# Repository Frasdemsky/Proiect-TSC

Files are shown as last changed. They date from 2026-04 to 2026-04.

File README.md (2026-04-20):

# Proiect-TSC - ceas

am tras trase printre pini in loc de via pentru ca nu stiam la acel moment ca pot pune via pe pin si sa fie in regula

Extras din BOM


Descrierea Funcționalității Hardware

Smartwatch-ul InkTime este construit în jurul microcontroller-ului nRF52840, ideal pentru aplicații open-source și comunicație eficientă energetic.

  Sistemul de Alimentare: Încărcarea se face prin mufa USB-C, care beneficiază de protecție ESD prin dioda USBLC6-2SC6Y. Integratul BQ25180YBGR încarcă bateria LiPo. Deoarece tensiunea bateriei variază pe măsură ce se descarcă, un convertor de tip Buck-Boost (RT6160AWSC) menține tensiunea sistemului stabilă la 3.3V. Circuitul integrat MAX17048G+T10 funcționează ca Fuel Gauge pe I2C pentru a raporta precis nivelul bateriei către microcontroller.
  
  Afișaj E-Paper: Este conectat la placă printr-un port dedicat (E-Paper Display Connector). Pentru o eficiență energetică maximă, alimentarea ecranului trece printr-un tranzistor MOSFET (DMG2305UX), permițând oprirea completă a curentului către display prin semnalul R_PWR_EPD atunci când imaginea nu se actualizează.
  
  Senzori și Interacțiune: Detecția orientării și a pașilor se face prin senzorul IMU BMA421, conectat prin interfața I2C (TP_SCL și TP_SDA). Pentru feedback la notificări sau apăsări de butoane, sistemul folosește un motor haptic controlat de driver-ul DRV2605YZFR. Interacțiunea manuală se face prin 3 butoane fizice (Up, Enter, Down) decuplate capacitiv.

Alocarea Pinilor nRF52840

  Magistrala I2C: Pinii de pe MCU asociați cu net-urile TP_SCL și TP_SDA conectează senzorul IMU BMA421, circuitul Fuel Gauge MAX17048 și driver-ul haptic DRV2605YZFR.
  Butoane: Butoanele SW_UP, SW_ENT și SW_DN sunt direcționate către pini GPIO ai nRF52840.
  
  Interfața SWD: Programarea și debugging-ul se realizează exclusiv prin pad-urile de test TP_SWDIO, TP_SWDCLK și TP_RESET.
  
  Control E-Paper: Comunicarea cu display-ul se face printr-o magistrală ce ajunge la conectorul E-Paper (include pini SPI și semnale de control). Controlul alimentării se realizează prin pinul conectat la R_PWR_EPD.

Am decis sa accept erorile de via pe pini pentru ca asa a spus Dan pe teams ca putem face. poze cu pcb-ul in carcasa se afla in folderul de images.
Puteam sa pun mai central acel MCU si sa am o organizare mai buna.

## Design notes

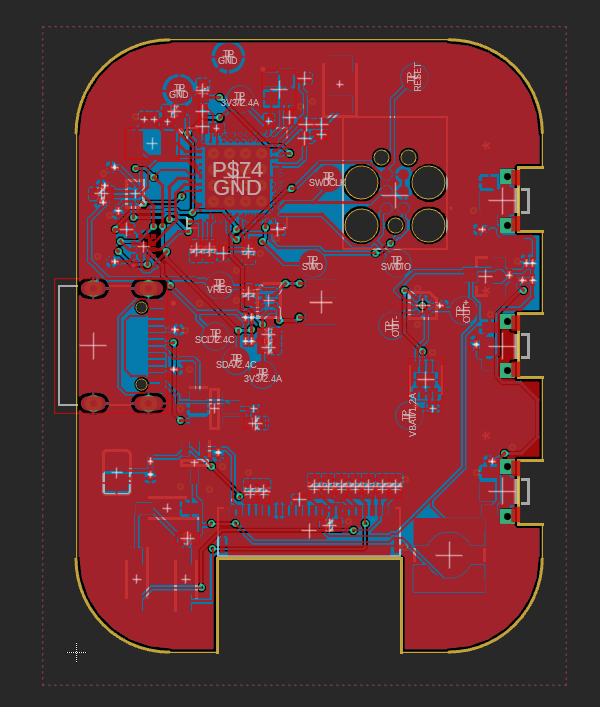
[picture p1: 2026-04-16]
Images/2DpcbPoligon.png

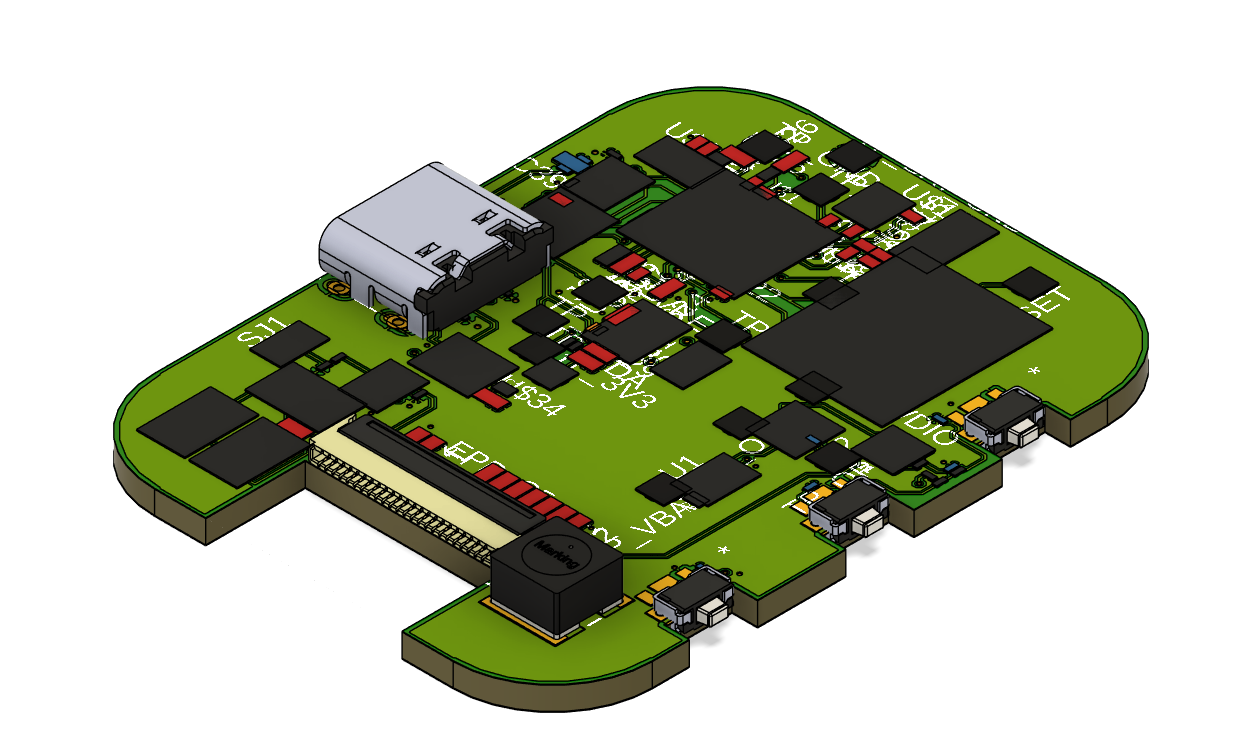
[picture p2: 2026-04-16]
Images/3DpcbGNDlayer.png

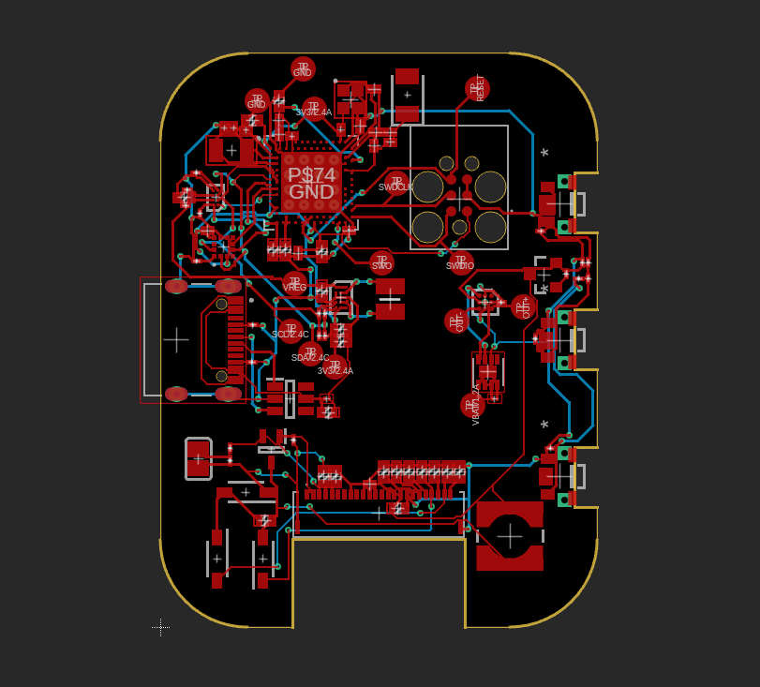
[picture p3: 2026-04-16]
Images/2DpcbVisible.png

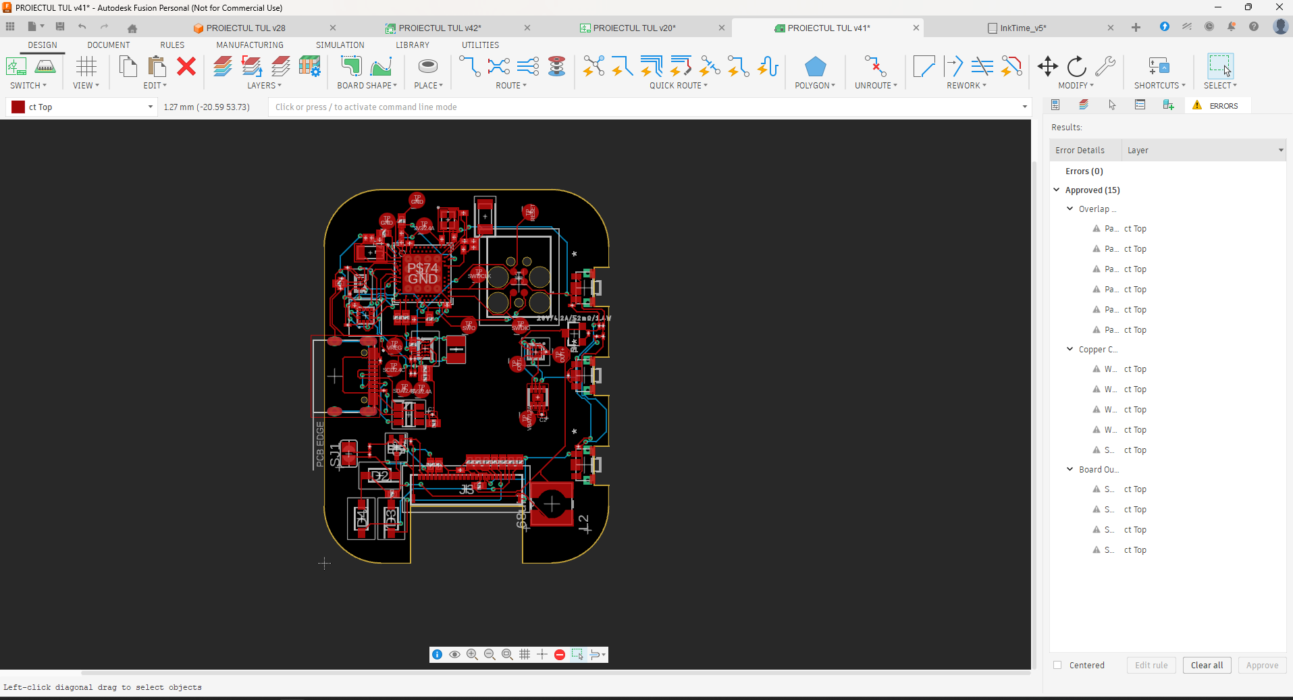
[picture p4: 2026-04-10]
Images/2D PCB.png

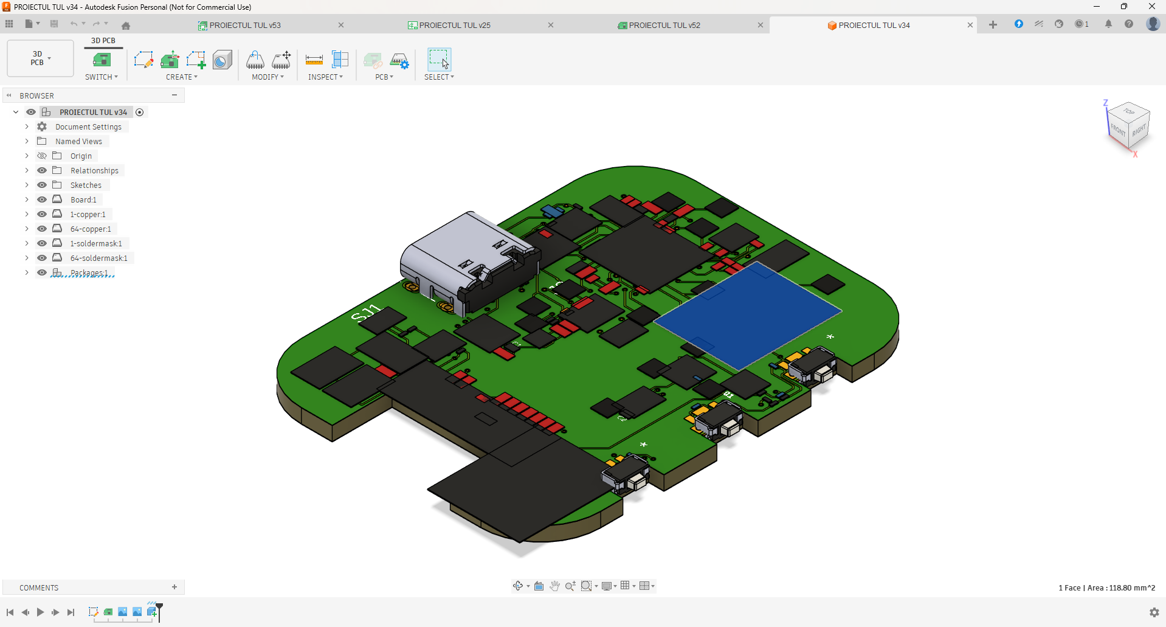
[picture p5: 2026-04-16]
Images/3D pcb.png

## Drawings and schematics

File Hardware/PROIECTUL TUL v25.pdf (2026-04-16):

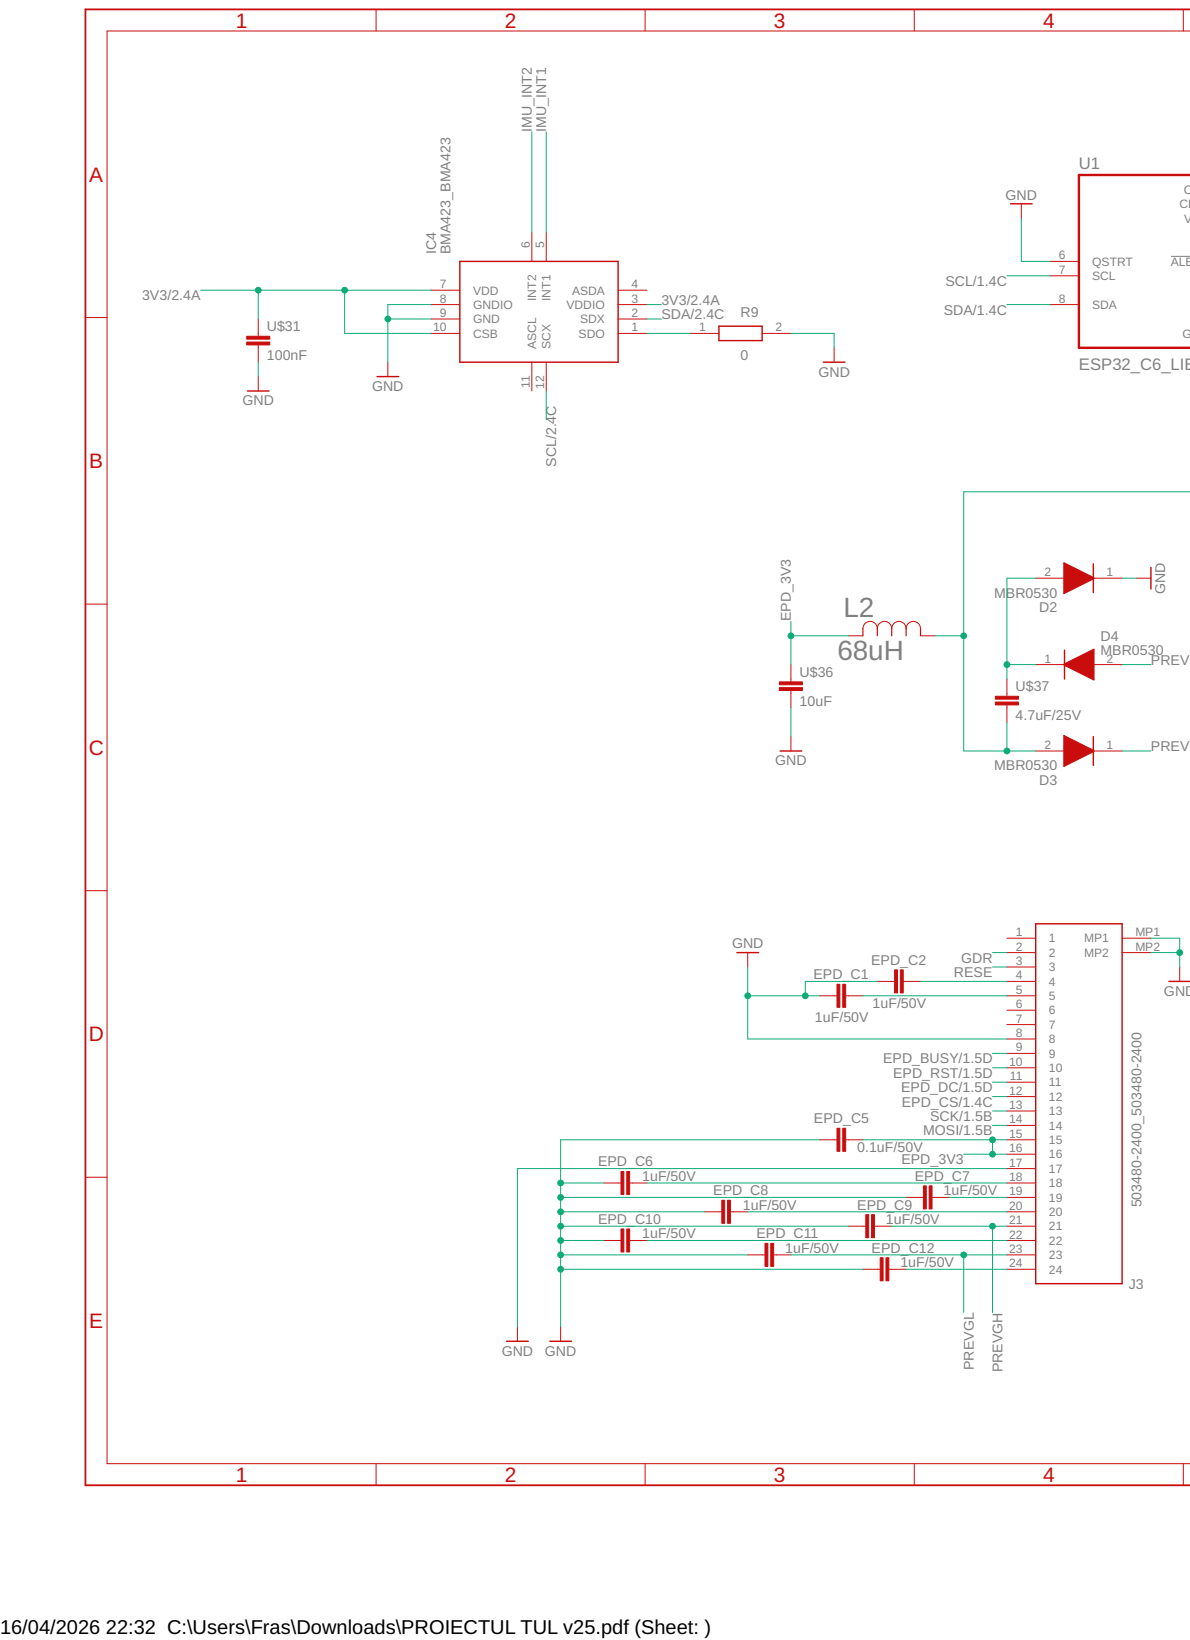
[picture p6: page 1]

1uF/50V EPD_C7 18

EPD_C8 | 1uF/50V 19
1uF/50V EPD_C9 | 20

EPD_C10 | | 1uF/50V 21

1uF/50V EPD_C11 | | 22

1uF/50V EPD_C12 | 23

16/04/2026 22:32 C:\Users\Fras\Downloads\PROIECTUL TUL v25.pdf (Sheet: )

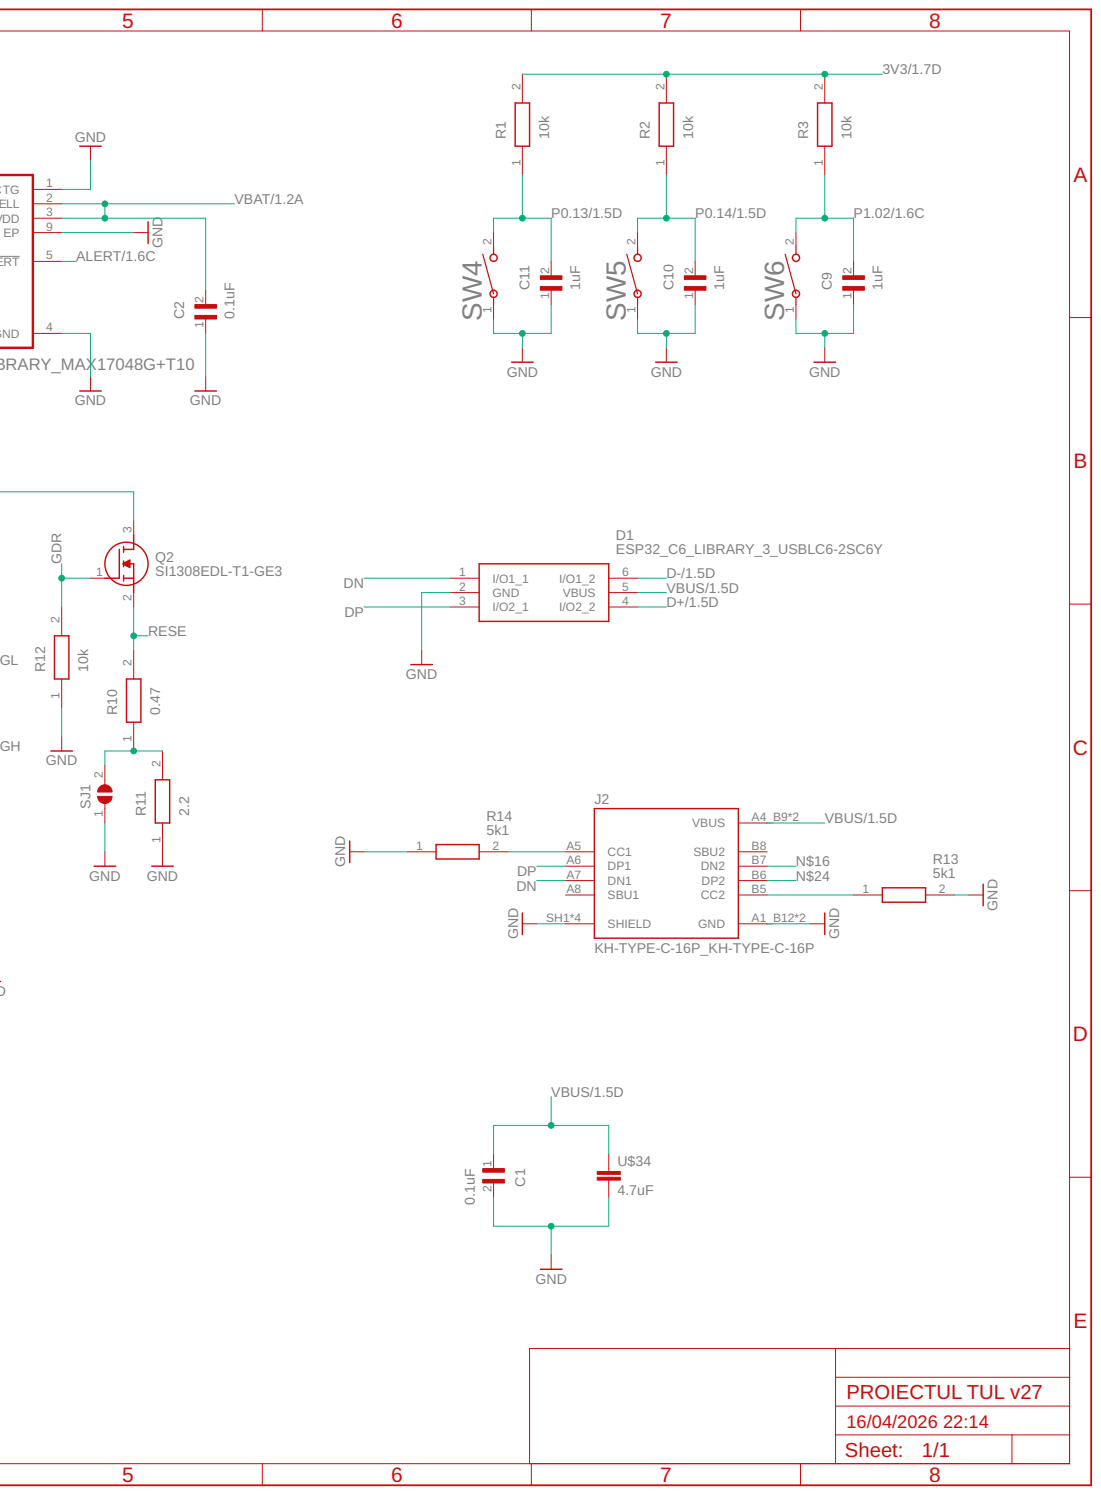
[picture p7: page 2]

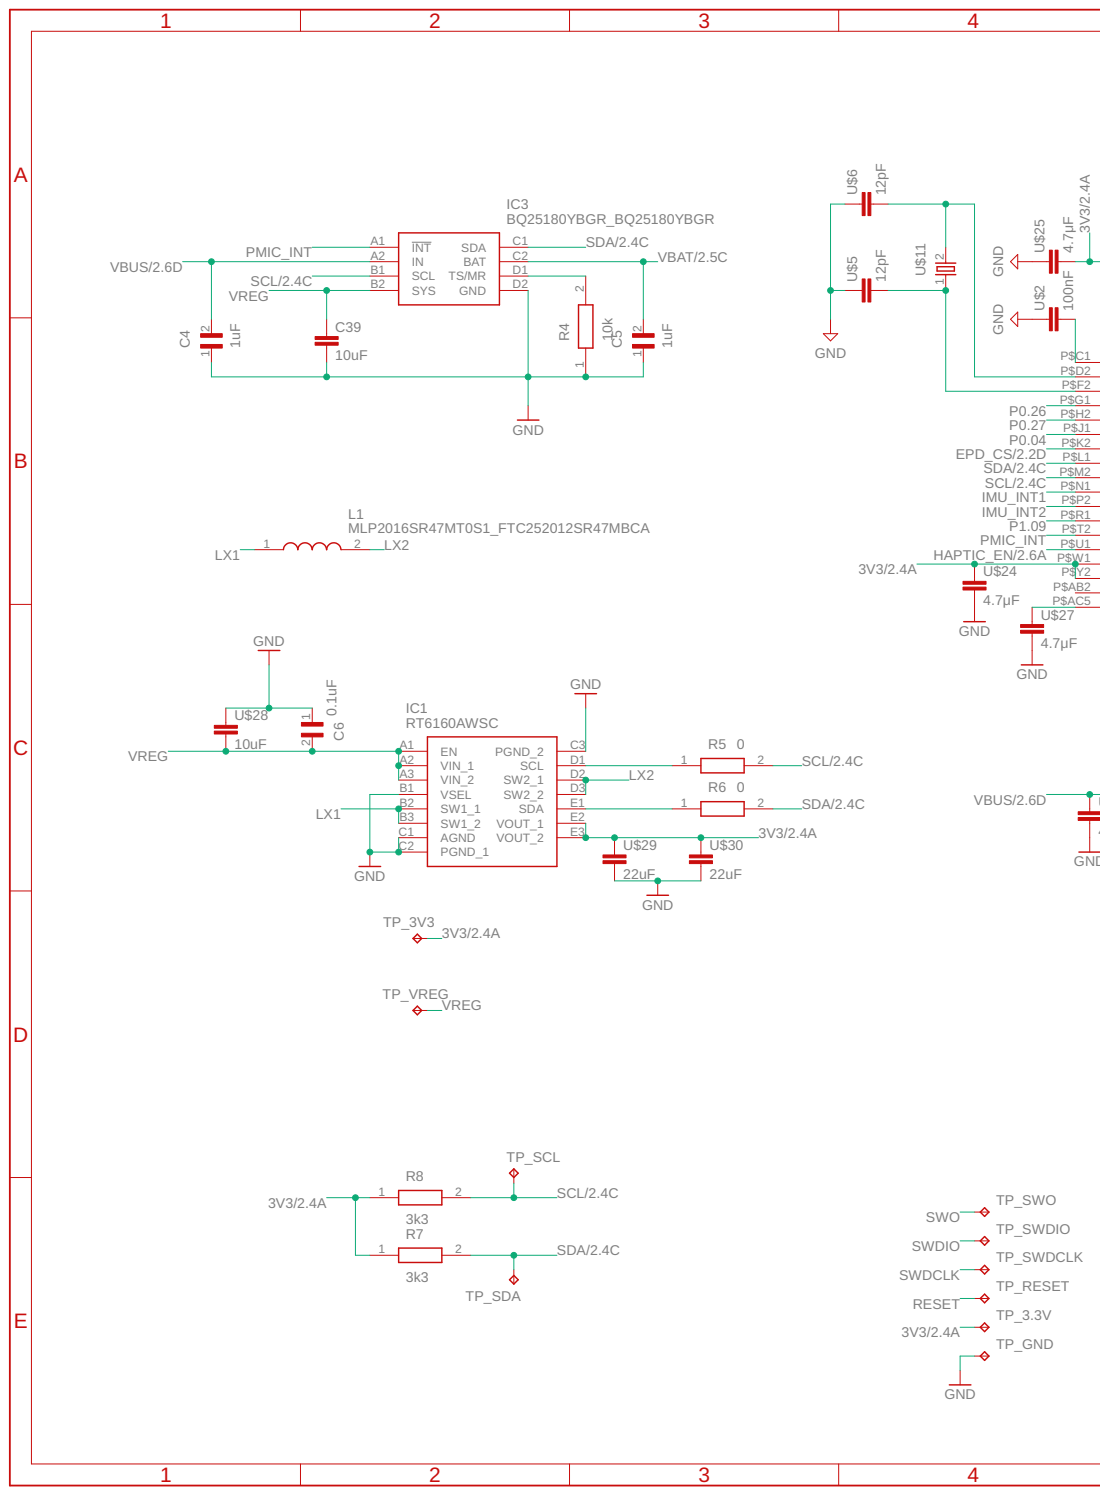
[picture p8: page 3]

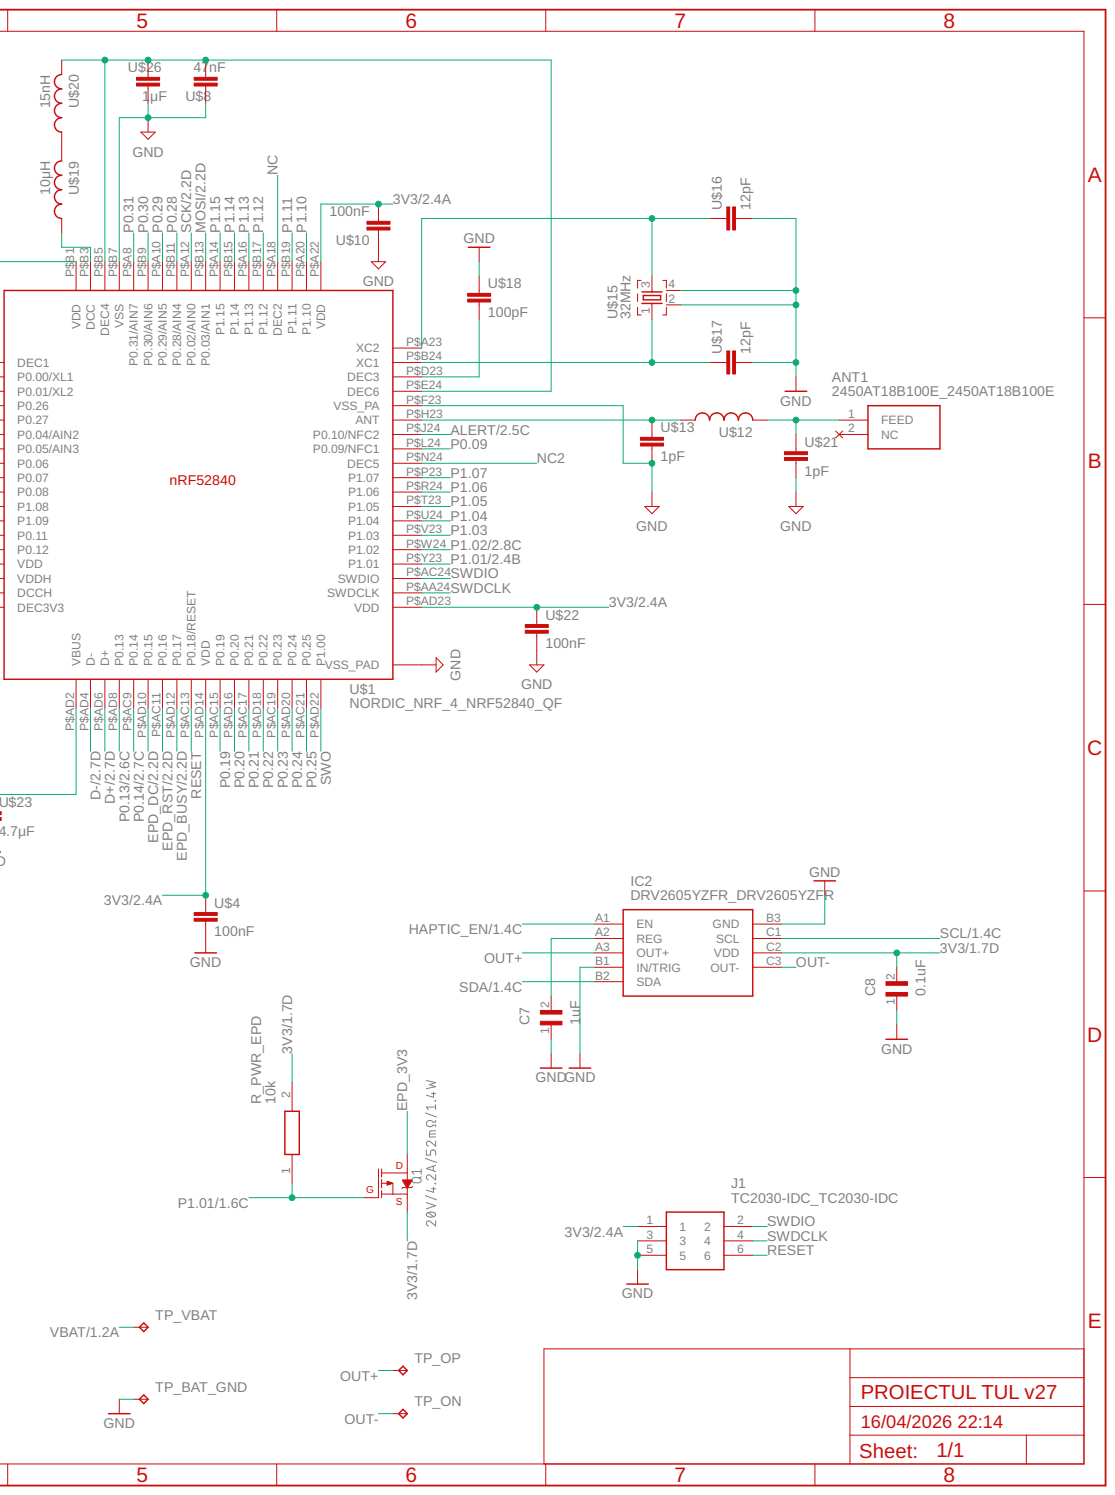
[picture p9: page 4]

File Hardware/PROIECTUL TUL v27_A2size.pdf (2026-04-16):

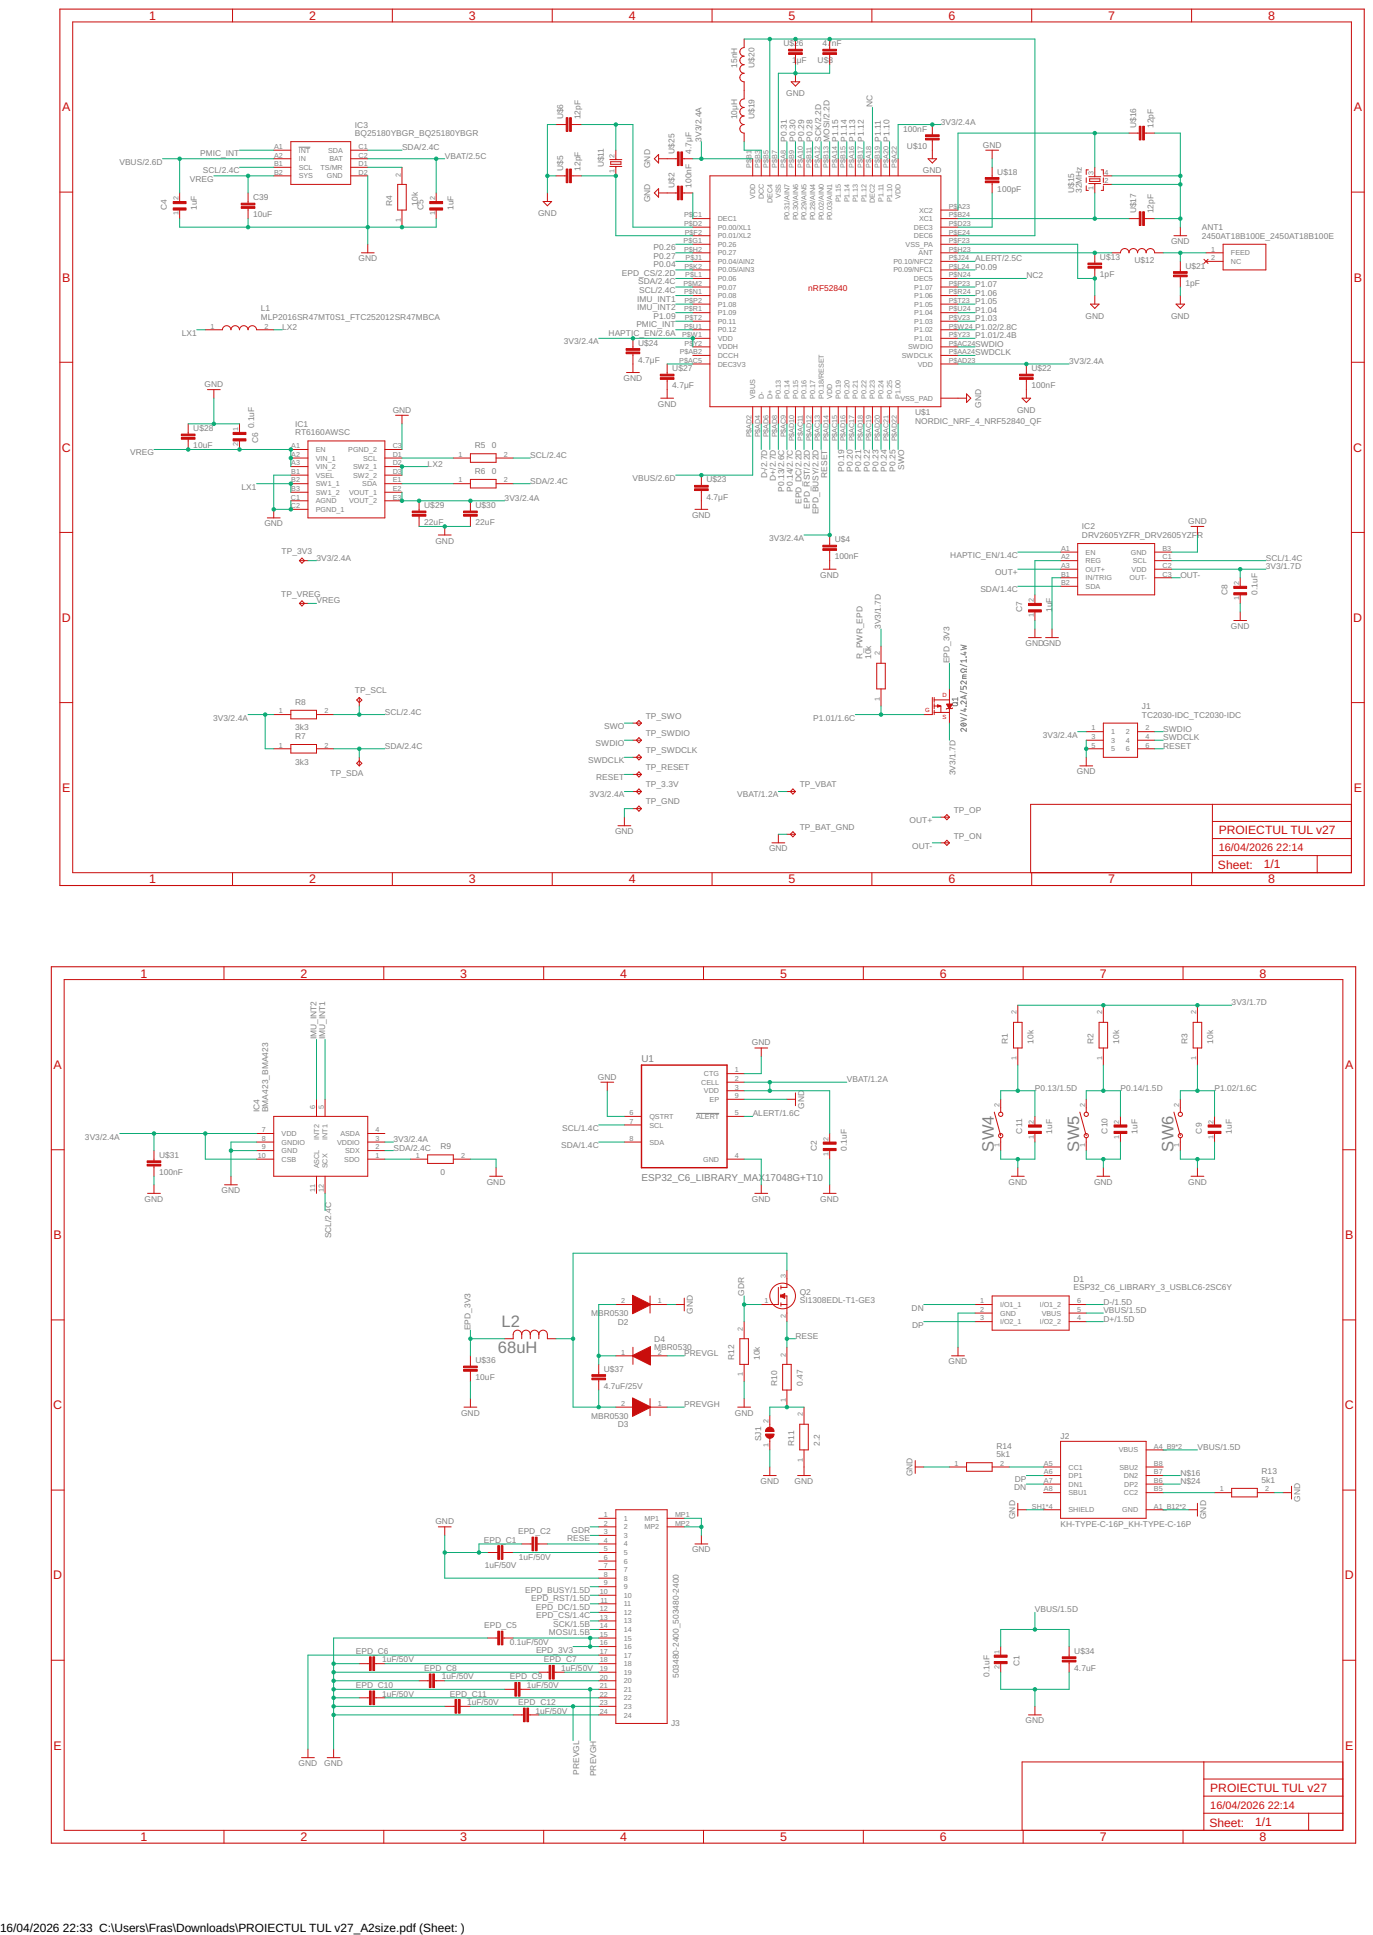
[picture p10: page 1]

1uF/50V EPD_C7 18

EPD_C8 | 1uF/50V 19
1uF/50V EPD_C9 | 20

EPD_C10 | | 1uF/50V 21

1uF/50V EPD_C11 | | 22

1uF/50V EPD_C12 | 23

16/04/2026 22:33 C:\Users\Fras\Downloads\PROIECTUL TUL v27_A2size.pdf (Sheet: )

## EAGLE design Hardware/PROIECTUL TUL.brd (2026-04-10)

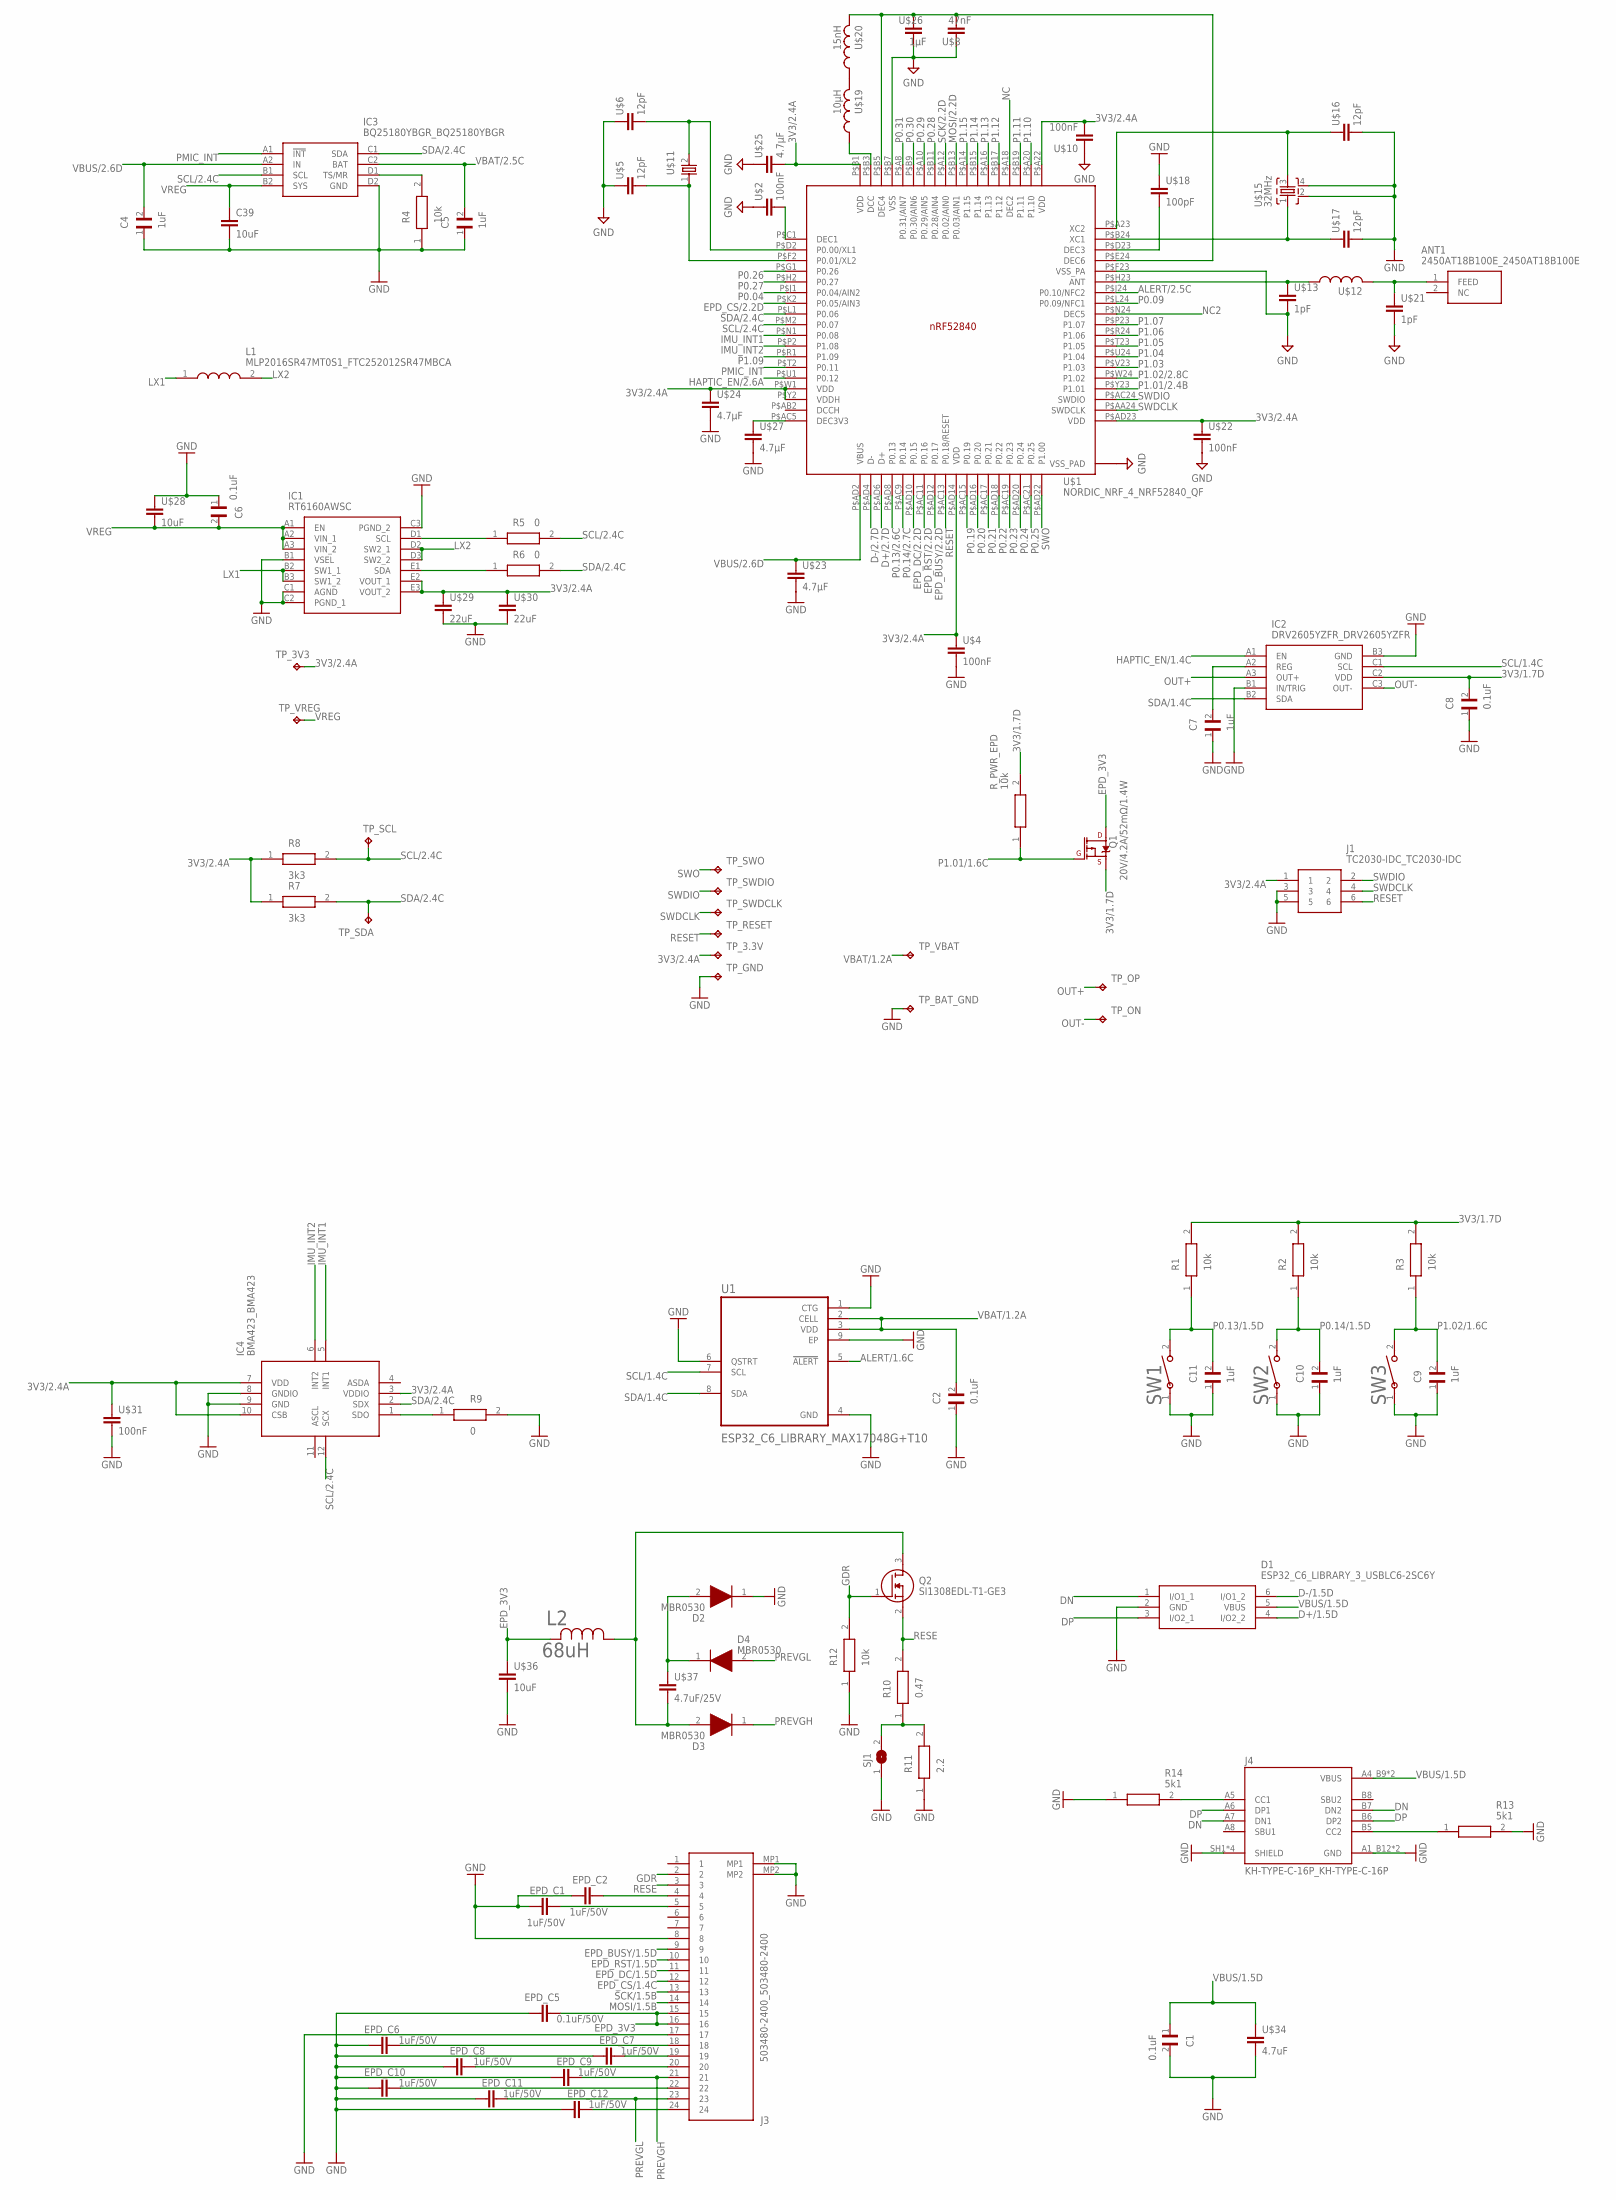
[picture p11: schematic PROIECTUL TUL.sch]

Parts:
ANT1: 2450AT18B100E_2450AT18B100E; 2450AT18B100E_ANTC3216X140N
C1, C2: 0.1uF; GRM011R60J152KE01L_2_CAPC0201X13N
C4, C5, C7, C9, C10, C11: 1uF; GRM011R60J152KE01L_1_0201
C6, C8: 0.1uF; GRM011R60J152KE01L_1_0201
C39: 10uF; NORDIC_NRF_3_RESC0402_L
D1: ESP32_C6_LIBRARY_3_USBLC6-2SC6Y; ESP32_C6_LIBRARY_3_SOT95P280X145-6N
D2, D3, D4: MBR0530; ESP32_C6_LIBRARY_5_SOD3716X135N
EPD_C1, EPD_C2, EPD_C6, EPD_C7, EPD_C8, EPD_C9, EPD_C10, EPD_C11, EPD_C12: 1uF/50V; NORDIC_NRF_3_RESC0402_L
EPD_C5: 0.1uF/50V; NORDIC_NRF_3_RESC0201_L
IC1: RT6160AWSC; RT6160AWSC_BGA15C40P3X5_140X230X60
IC2: DRV2605YZFR_DRV2605YZFR; DRV2605YZFR_BGA9C50P3X3_144X144X62
IC3: BQ25180YBGR_BQ25180YBGR; BQ25180YBGR_BGA8C40P2X4_100X155X50
IC4: BMA423_BMA423
J1: TC2030-IDC_TC2030-IDC; TC2030-IDC_TC2030IDC
J3: 503480-2400_503480-2400; 503480-2400_5034802400
J4: KH-TYPE-C-16P_KH-TYPE-C-16P; KH-TYPE-C-16P_KINGHELM_KH-TYPE-C-16P
L1: MLP2016SR47MT0S1_FTC252012SR47MBCA; MLP2016SR47MT0S1_INDC2016X100N
L2: 68uH; ESP32_C6_LIBRARY_2_IND_4828-WE-TPC_WRE
Q1: 20V/4.2A/52mΩ/1.4W; ESP32_C6_LIBRARY_4_ESP32_C6_LIBRARY_4_ESP32_C6_LIBRARY_4_ES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
Q2: SI1308EDL-T1-GE3; ESP32_C6_LIBRARY_6_SOT65P210X110-3N
R1, R3, R4, R12: 10k; ERA-1AEB3401C_0201
R2: 10k; CPF0201D7K68C1_0201
R5: 0; CPF0201D7K68C1_0201
R6, R9: 0; ERA-1AEB3401C_0201
R7, R8: 3k3; ERA-1AEB3401C_0201
R10: 0.47; ERA-1AEB3401C_0201
R11: 2.2; ERA-1AEB3401C_0201
R13, R14: 5k1; ERA-1AEB3401C_0201
R_PWR_EPD: 10k; ERA-1AEB3401C_0201
SJ1: ESP32_C6_LIBRARY_7_JUMPER_SJ
SW1, SW2, SW3: 2025-10-22_07-23-44_LIBRARY_EVP-AKE31ASW_EVP-AKE3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; 2025-10-22_07-23-44_LIBRARY_SW_EVP-AKE31A_PAN
TP_3.3V, TP_3V3: HECTOR_WATCH_1_TPTP20R; HECTOR_WATCH_1_TP20R
TP_BAT_GND: HECTOR_WATCH_1_TPTP20R; HECTOR_WATCH_1_TP20R
TP_GND: HECTOR_WATCH_1_TPTP20R; HECTOR_WATCH_1_TP20R
TP_ON: HECTOR_WATCH_1_TPTP20R; HECTOR_WATCH_1_TP20R
TP_OP: HECTOR_WATCH_1_TPTP20R; HECTOR_WATCH_1_TP20R
TP_RESET: HECTOR_WATCH_1_TPTP20R; HECTOR_WATCH_1_TP20R
TP_SCL: HECTOR_WATCH_1_TPTP20R; HECTOR_WATCH_1_TP20R
TP_SDA: HECTOR_WATCH_1_TPTP20R; HECTOR_WATCH_1_TP20R
TP_SWDCLK: HECTOR_WATCH_1_TPTP20R; HECTOR_WATCH_1_TP20R
TP_SWDIO: HECTOR_WATCH_1_TPTP20R; HECTOR_WATCH_1_TP20R
TP_SWO: HECTOR_WATCH_1_TPTP20R; HECTOR_WATCH_1_TP20R
TP_VBAT: HECTOR_WATCH_1_TPTP20R; HECTOR_WATCH_1_TP20R
TP_VREG: HECTOR_WATCH_1_TPTP20R; HECTOR_WATCH_1_TP20R
U1: ESP32_C6_LIBRARY_MAX17048G+T10; ESP32_C6_LIBRARY_SON50P200X200X80-9N
U$1: NORDIC_NRF_4_NRF52840_QF; NORDIC_NRF_4_AQFN50P700X700X85_HS-74N
U$2, U$10: 100nF; RESC0201_L
U$4, U$22, U$31: 100nF; NORDIC_NRF_3_RESC0201_L
U$5, U$6: 12pF; RESC0201_L
U$8: 47nF; RESC0201_L
U$11: NORDIC_NRF_1_XTAL_32KHZ; NORDIC_NRF_1_XTAL_3215_N
U$12: NORDIC_NRF_2_INDUCTOR_0201_L; NORDIC_NRF_2_RESC0201_L
U$13, U$21: 1pF; NORDIC_NRF_3_RESC0201_L
U$15: 32MHz; NORDIC_NRF_BT-XTAL_2016_N
U$16, U$17: 12pF; NORDIC_NRF_3_RESC0201_L
U$18: 100pF; NORDIC_NRF_3_RESC0201_L
U$19: 10μH; NORDIC_NRF_2_RESC0201_L
U$20: 15nH; NORDIC_NRF_2_RESC0201_L
U$23, U$24, U$25, U$27: 4.7μF; NORDIC_NRF_3_RESC0402_L
U$26: 1μF; NORDIC_NRF_3_RESC0402_L
U$28, U$36: 10uF; NORDIC_NRF_3_RESC0402_L
U$29, U$30: 22uF; NORDIC_NRF_3_RESC0402_L
U$34: 4.7uF; NORDIC_NRF_3_RESC0402_L
U$37: 4.7uF/25V; NORDIC_NRF_3_RESC0402_L

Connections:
3V3/1.7D: C8.2, IC2.C2 (VDD), Q1.2 (S), R1.2, R2.2, R3.2, R_PWR_EPD.2
3V3/2.4A: IC1.E2 (VOUT_1), IC1.E3 (VOUT_2), IC4.3 (VDDIO), IC4.7 (VDD), IC4.10 (CSB), J1.1, R7.1, R8.1, TP_3.3V.TP, TP_3V3.TP, U$1.P$A22 (VDD), U$1.P$AD14 (VDD), U$1.P$AD23 (VDD), U$1.P$B1 (VDD), U$1.P$W1 (VDD), U$1.P$Y2 (VDDH), U$4.1, U$10.2, U$22.1, U$24.1, U$25.2, U$29.1, U$30.1, U$31.1
ALERT/1.6C: U1.5 (!ALERT)
ALERT/2.5C: U$1.P$J24 (P0.10/NFC2)
D+/1.5D: D1.4 (I/O2_2)
D+/2.7D: U$1.P$AD6 (D+)
D-/1.5D: D1.6 (I/O1_2)
D-/2.7D: U$1.P$AD4 (D-)
DN: D1.1 (I/O1_1), J4.A7 (DN1), J4.B7 (DN2)
DP: D1.3 (I/O2_1), J4.A6 (DP1), J4.B6 (DP2)
EPD_3V3: EPD_C5.2, J3.15, J3.16, L2.2, Q1.3 (D), U$36.1
EPD_BUSY/1.5D: J3.9
EPD_BUSY/2.2D: U$1.P$AD12 (P0.17)
EPD_CS/1.4C: J3.12
EPD_CS/2.2D: U$1.P$K2 (P0.05/AIN3)
EPD_DC/1.5D: J3.11
EPD_DC/2.2D: U$1.P$AD10 (P0.15)
EPD_RST/1.5D: J3.10
EPD_RST/2.2D: U$1.P$AC11 (P0.16)
GDR: J3.2, Q2.1 (G), R12.2
GND: C1.2, C2.1, C4.1, C5.1, C6.1, C7.1, C8.1, C9.1, C10.1, C11.1, C39.2, D1.2 (GND), D2.1 (K), EPD_C1.1, EPD_C2.1, EPD_C5.1, EPD_C6.1, EPD_C7.1, EPD_C8.1, EPD_C9.1, EPD_C10.1, EPD_C11.1, EPD_C12.1, IC1.B1 (VSEL), IC1.C1 (AGND), IC1.C2 (PGND_1), IC1.C3 (PGND_2), IC2.B1 (IN/TRIG), IC2.B3 (GND), IC3.D2 (GND), IC4.8 (GNDIO), IC4.9 (GND), J1.3, J1.5, J3.8, J3.17, J3.MP1, J3.MP2, J4.A1_B12 (GND), J4.A12_B1 (GND), J4.SH1 (SHIELD), J4.SH2 (SHIELD), J4.SH3 (SHIELD), J4.SH4 (SHIELD), R4.1, R9.2, R11.1, R12.1, R13.2, R14.1, SJ1.1, SW1.1, SW2.1, SW3.1, TP_BAT_GND.TP, TP_GND.TP, U1.1 (CTG), U1.4 (GND), U1.6 (QSTRT), U1.9 (EP), U$1.P$74 (VSS_PAD), U$1.P$75 (VSS_PAD), U$1.P$76 (VSS_PAD), U$1.P$77 (VSS_PAD), U$1.P$78 (VSS_PAD), U$1.P$79 (VSS_PAD), U$1.P$80 (VSS_PAD), U$1.P$81 (VSS_PAD), U$1.P$82 (VSS_PAD), U$1.P$83 (VSS_PAD), U$1.P$84 (VSS_PAD), U$1.P$85 (VSS_PAD), U$1.P$86 (VSS_PAD), U$1.P$87 (VSS_PAD), U$1.P$88 (VSS_PAD), U$1.P$89 (VSS_PAD), U$1.P$90 (VSS_PAD), U$1.P$B7 (VSS), U$1.P$F23 (VSS_PA), U$2.1, U$4.2, U$5.1, U$6.1, U$8.1, U$10.1, U$13.2, U$15.2, U$15.4, U$16.2, U$17.2, U$18.1, U$21.2, U$22.2, U$23.2, U$24.2, U$25.1, U$26.2, U$27.2, U$28.1, U$29.2, U$30.2, U$31.2, U$34.2, U$36.2
HAPTIC_EN/1.4C: IC2.A1 (EN)
HAPTIC_EN/2.6A: U$1.P$U1 (P0.12)
IMU_INT1: IC4.5 (INT1), U$1.P$N1 (P0.08)
IMU_INT2: IC4.6 (INT2), U$1.P$P2 (P1.08)
LX1: IC1.B2 (SW1_1), IC1.B3 (SW1_2), L1.1
LX2: IC1.D2 (SW2_1), IC1.D3 (SW2_2), L1.2
MOSI/1.5B: J3.14
MOSI/2.2D: U$1.P$B13 (P0.03/AIN1)
unnamed: U$1.P$D2 (P0.00/XL1), U$6.2, U$11.2
unnamed: U$1.P$F2 (P0.01/XL2), U$5.2, U$11.1
unnamed: U$1.P$H23 (ANT), U$12.1, U$13.1
unnamed: U$1.P$B3 (DCC), U$19.1
unnamed: U$1.P$B5 (DEC4), U$1.P$E24 (DEC6), U$8.2, U$20.2, U$26.1
unnamed: IC1.E1 (SDA), R6.1
unnamed: U$1.P$D23 (DEC3), U$18.2
unnamed: U$1.P$A23 (XC2), U$15.3, U$16.1
unnamed: U$1.P$B24 (XC1), U$15.1, U$17.1
unnamed: U$19.2, U$20.1
unnamed: ANT1.1 (FEED), U$12.2, U$21.1
unnamed: U$1.P$AC5 (DEC3V3), U$27.1
unnamed: IC1.D1 (SCL), R5.1
unnamed: IC4.1 (SDO), R9.1
unnamed: EPD_C2.2, J3.4
unnamed: IC3.D1 (TS/MR), R4.2
unnamed: EPD_C1.2, J3.5
unnamed: EPD_C7.2, J3.19
unnamed: C7.2, IC2.A2 (REG)
unnamed: EPD_C6.2, J3.18
unnamed: EPD_C8.2, J3.20
unnamed: EPD_C12.2, J3.24
unnamed: D2.2 (A), D4.1 (K), U$37.1
unnamed: EPD_C10.2, J3.22
unnamed: J4.A5 (CC1), R14.2
unnamed: J4.B5 (CC2), R13.1
unnamed: D3.2 (A), L2.1, Q2.3 (D), U$37.2
unnamed: R10.1, R11.2, SJ1.2
NC: U$1.P$A18 (DEC2)
NC2: U$1.P$N24 (DEC5)
OUT+: IC2.A3 (OUT+), TP_OP.TP
OUT-: IC2.C3 (OUT-), TP_ON.TP
P0.04: U$1.P$J1 (P0.04/AIN2)
P0.09: U$1.P$L24 (P0.09/NFC1)
P0.13/1.5D: C11.2, R1.1, SW1.2
P0.13/2.6C: U$1.P$AD8 (P0.13)
P0.14/1.5D: C10.2, R2.1, SW2.2
P0.14/2.7C: U$1.P$AC9 (P0.14)
P0.19: U$1.P$AC15 (P0.19)
P0.20: U$1.P$AD16 (P0.20)
P0.21: U$1.P$AC17 (P0.21)
P0.22: U$1.P$AD18 (P0.22)
P0.23: U$1.P$AC19 (P0.23)
P0.24: U$1.P$AD20 (P0.24)
P0.25: U$1.P$AC21 (P0.25)
P0.26: U$1.P$G1 (P0.26)
P0.27: U$1.P$H2 (P0.27)
P0.28: U$1.P$B11 (P0.28/AIN4)
P0.29: U$1.P$A10 (P0.29/AIN5)
P0.30: U$1.P$B9 (P0.30/AIN6)
P0.31: U$1.P$A8 (P0.31/AIN7)
P1.01/1.6C: Q1.1 (G), R_PWR_EPD.1
P1.01/2.4B: U$1.P$Y23 (P1.01)
P1.02/1.6C: C9.2, R3.1, SW3.2
P1.02/2.8C: U$1.P$W24 (P1.02)
P1.03: U$1.P$V23 (P1.03)
P1.04: U$1.P$U24 (P1.04)
P1.05: U$1.P$T23 (P1.05)
P1.06: U$1.P$R24 (P1.06)
P1.07: U$1.P$P23 (P1.07)
P1.09: U$1.P$R1 (P1.09)
P1.10: U$1.P$A20 (P1.10)
P1.11: U$1.P$B19 (P1.11)
P1.12: U$1.P$B17 (P1.12)
P1.13: U$1.P$A16 (P1.13)
P1.14: U$1.P$B15 (P1.14)
P1.15: U$1.P$A14 (P1.15)
PMIC_INT: IC3.A1 (!INT), U$1.P$T2 (P0.11)
PREVGH: D3.1 (K), EPD_C9.2, J3.21
PREVGL: D4.2 (A), EPD_C11.2, J3.23
RESE: J3.3, Q2.2 (S), R10.2
RESET: J1.6, TP_RESET.TP, U$1.P$AC13 (P0.18/RESET)
SASSS: U$1.P$C1 (DEC1), U$2.2
SCK/1.5B: J3.13
SCK/2.2D: U$1.P$A12 (P0.02/AIN0)
SCL/1.4C: IC2.C1 (SCL), U1.7 (SCL)
SCL/2.4C: IC3.B1 (SCL), IC4.12 (SCX), R5.2, R8.2, TP_SCL.TP, U$1.P$M2 (P0.07)
SDA/1.4C: IC2.B2 (SDA), U1.8 (SDA)
SDA/2.4C: IC3.C1 (SDA), IC4.2 (SDX), R6.2, R7.2, TP_SDA.TP, U$1.P$L1 (P0.06)
SWDCLK: J1.4, TP_SWDCLK.TP, U$1.P$AA24 (SWDCLK)
SWDIO: J1.2, TP_SWDIO.TP, U$1.P$AC24 (SWDIO)
SWO: TP_SWO.TP, U$1.P$AD22 (P1.00)
VBAT/1.2A: C2.2, TP_VBAT.TP, U1.2 (CELL), U1.3 (VDD)
VBAT/2.5C: C5.2, IC3.C2 (BAT)
VBUS/1.5D: C1.1, D1.5 (VBUS), J4.A4_B9 (VBUS), J4.A9_B4 (VBUS), U$34.1
VBUS/2.6D: C4.2, IC3.A2 (IN), U$1.P$AD2 (VBUS), U$23.1
VREG: C6.2, C39.1, IC1.A1 (EN), IC1.A2 (VIN_1), IC1.A3 (VIN_2), IC3.B2 (SYS), TP_VREG.TP, U$28.2

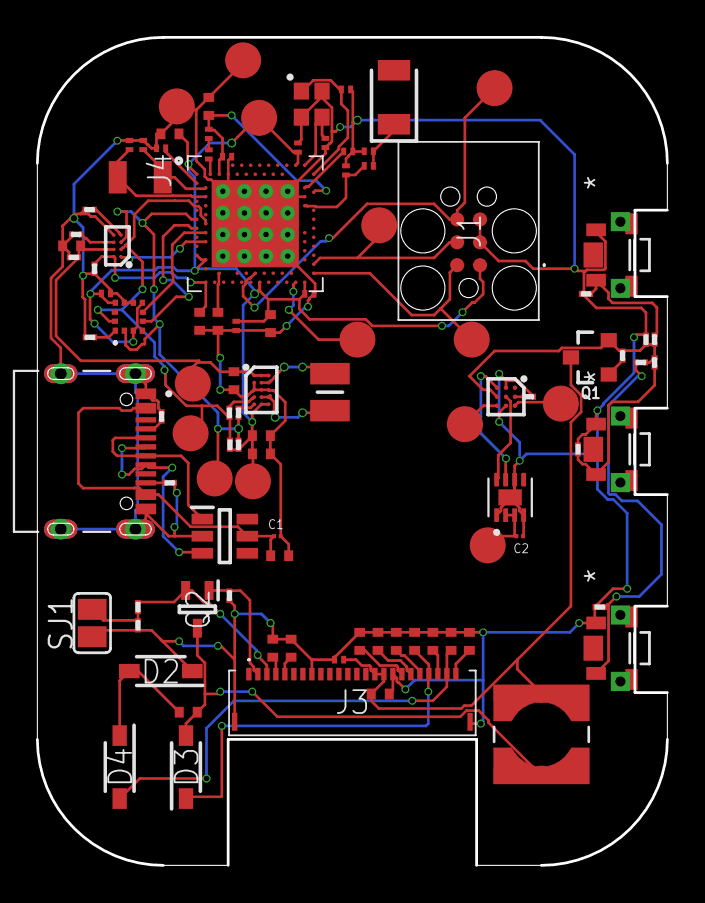
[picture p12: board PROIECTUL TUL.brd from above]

Board: 2 copper layers, 35.0 x 46.0 mm, 101 parts (0 on the bottom side), 63 nets.

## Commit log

2026-04-16 Add files via upload
    fara stratul de polinom
2026-04-16 varianta vizibila, fara poligon de GND
2026-04-16 variantele care cred ca-s finale
    [PROIECTUL TUL.sch, PROIECTUL_TUL.brd]
2026-04-20 Revise README with detailed component descriptions
    Updated technical specifications and details about the smartwatch's components, including power system, display, sensors, and pin allocation. Added notes on design decisions and PCB images.

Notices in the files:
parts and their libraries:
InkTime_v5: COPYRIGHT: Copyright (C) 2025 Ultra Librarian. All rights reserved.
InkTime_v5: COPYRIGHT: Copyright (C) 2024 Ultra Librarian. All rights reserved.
